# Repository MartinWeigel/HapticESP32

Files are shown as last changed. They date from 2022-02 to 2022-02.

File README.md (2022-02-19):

# HapticESP32

This PCB provides a maximum of eight ERM/LRA drivers and two transistors to control binary actuators.
All haptic actuators can be controlled through an [Adafruit Feather HUZZAH32](https://www.adafruit.com/product/3405) microcontroller.

All SMDs are on one-side of the PCB only to reduce costs for the assembly service.

This board was designed using [KiCad 6.0](http://www.kicad.org).

## Design
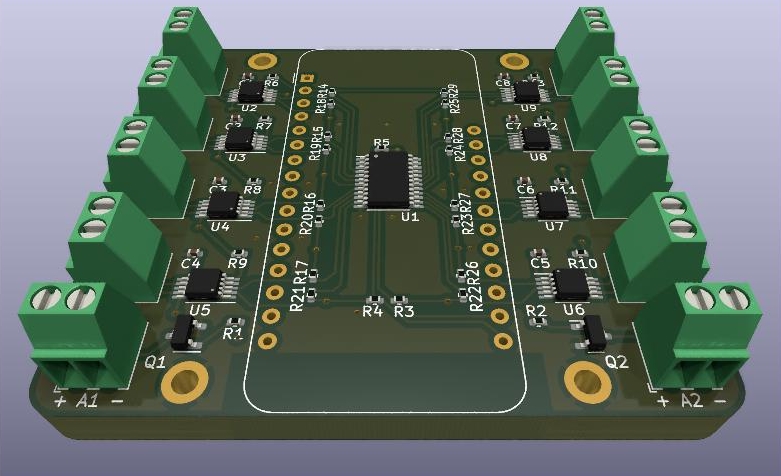
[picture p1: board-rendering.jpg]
Rendering of the board


## Parts
The part list is divided into two sections, the first one contains the parts if you decide to only solder the through-hole components yourself. The second BOM contains the SMD components.

### Through-hole components
Part                   | Quantity | Description
-----------------------|----------|-----------------------
Feather HUZZAH32       | 1        | ESP32 Microcontroller
Phoenix MPT-0,5-2-2.54 | 10       | 2-pin Terminalblock

### SMD components
Part               | Quantity | Description
-------------------|----------|-----------------
TCA9548APWR        | 1        | I2C Multiplexer
DRV2605LDGSR       | 8        | ERM/LRA Driver
MMBT5550LT1G       | 2        | NPN Transistor
Resistor 0402 1k   | 2        | Generic Resistor
Resistor 0402 4.7k | 27       | Generic Resistor
Capacitor 0402 1uF | 8        | Generic Capacitor

## License
<br />This work is licensed under a <a rel="license" href="http://creativecommons.org/licenses/by/4.0/">Creative Commons Attribution 4.0 International License</a>.

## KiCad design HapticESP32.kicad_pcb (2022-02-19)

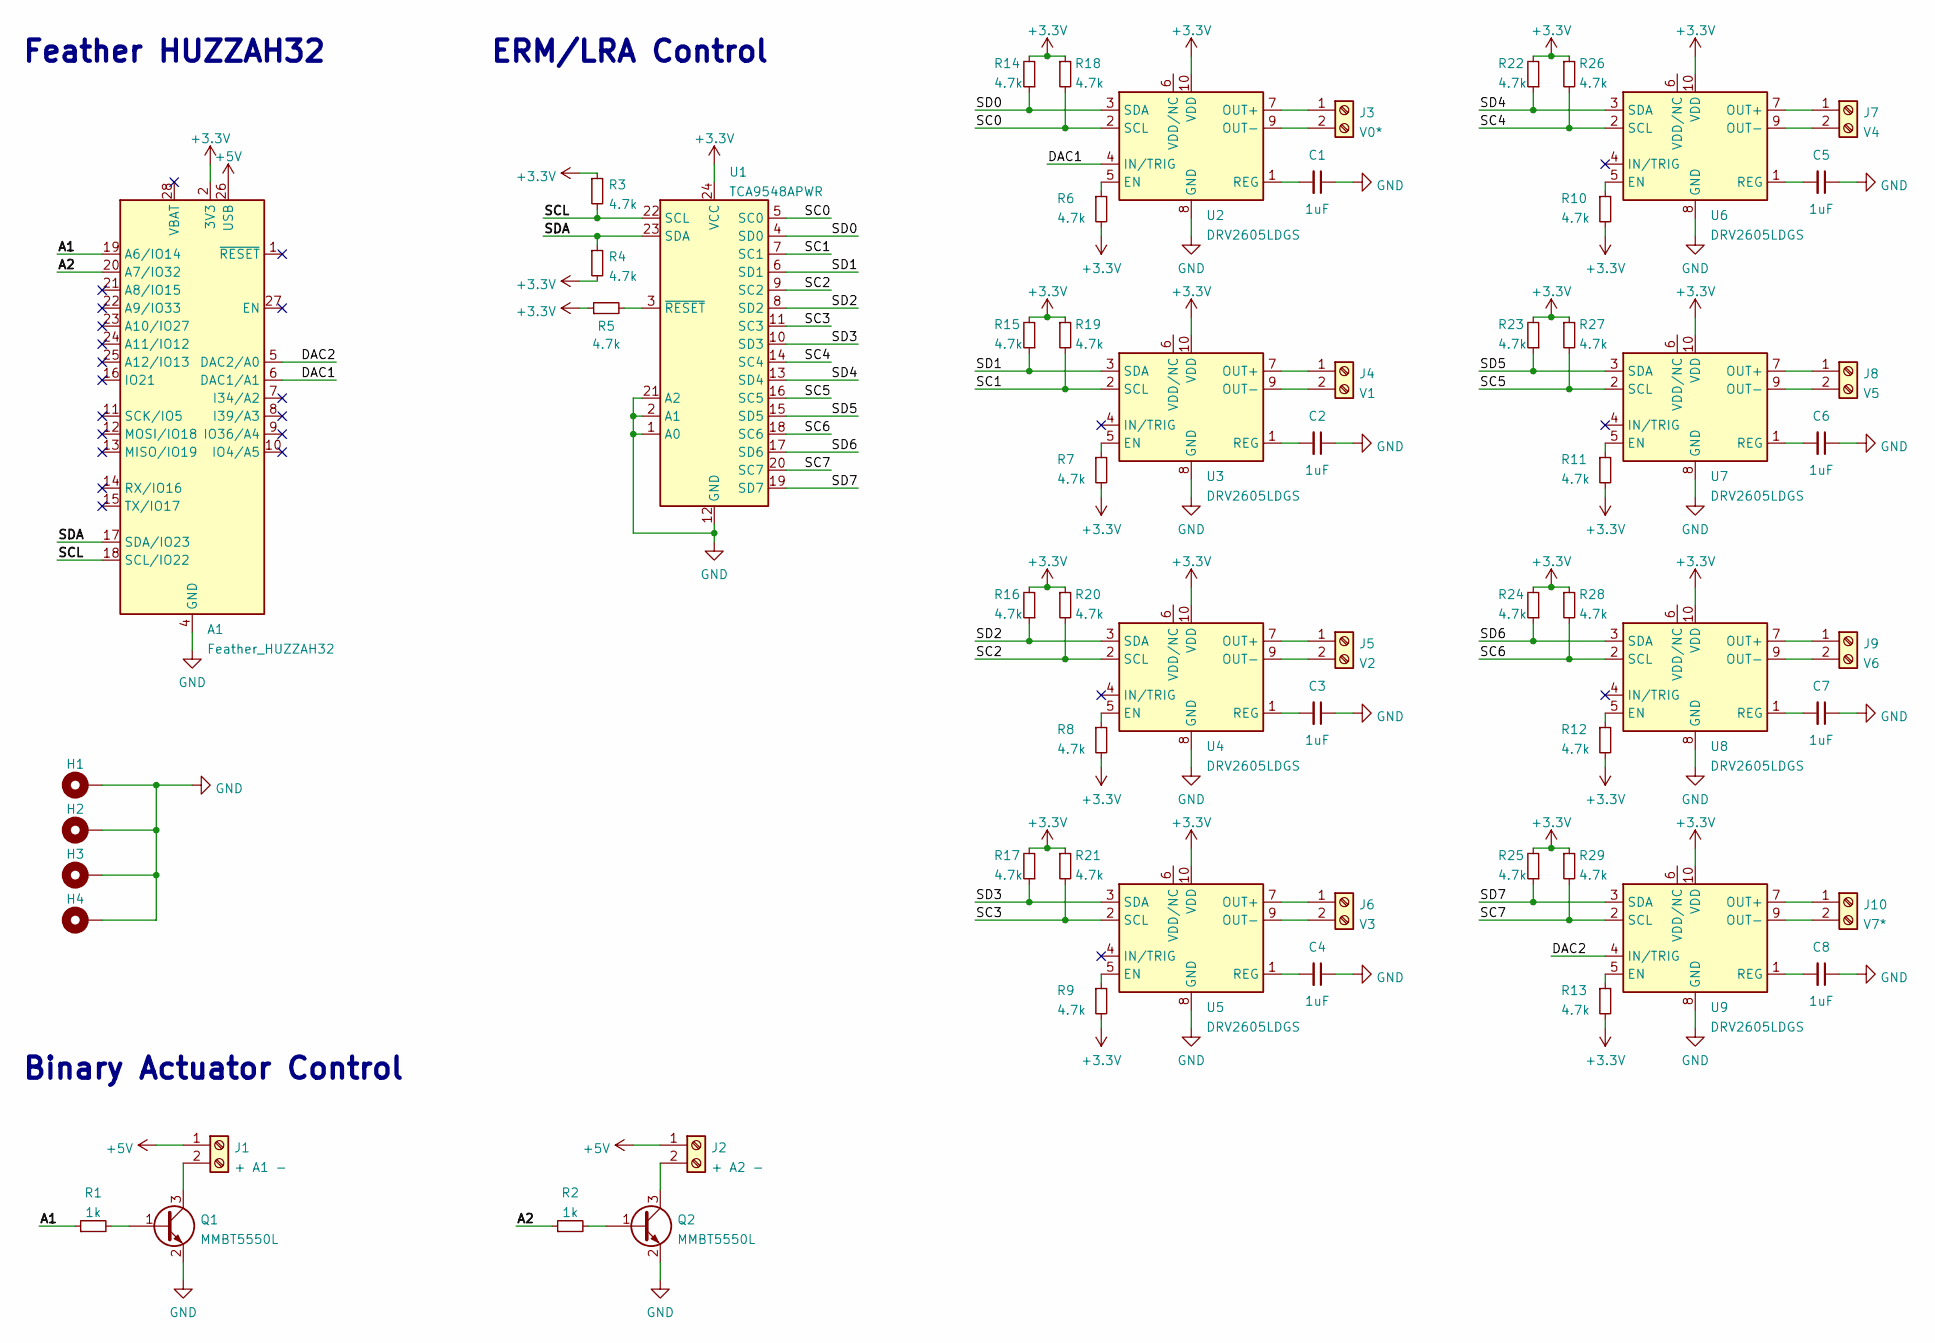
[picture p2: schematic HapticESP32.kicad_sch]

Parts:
A1: Feather_HUZZAH32; Adafruit_Feather
C1, C2, C3, C4, C5, C6, C7, C8: 1uF; C_0402_1005Metric
H1, H2, H3, H4: MountingHole_Pad; MountingHole_2.2mm_M2_DIN965_Pad
J1: + A1 -; TerminalBlock_Phoenix_MPT-0,5-2-2.54_1x02_P2.54mm_Horizontal
J2: + A2 -; TerminalBlock_Phoenix_MPT-0,5-2-2.54_1x02_P2.54mm_Horizontal
J3: V0*; TerminalBlock_Phoenix_MPT-0,5-2-2.54_1x02_P2.54mm_Horizontal
J4: V1; TerminalBlock_Phoenix_MPT-0,5-2-2.54_1x02_P2.54mm_Horizontal
J5: V2; TerminalBlock_Phoenix_MPT-0,5-2-2.54_1x02_P2.54mm_Horizontal
J6: V3; TerminalBlock_Phoenix_MPT-0,5-2-2.54_1x02_P2.54mm_Horizontal
J7: V4; TerminalBlock_Phoenix_MPT-0,5-2-2.54_1x02_P2.54mm_Horizontal
J8: V5; TerminalBlock_Phoenix_MPT-0,5-2-2.54_1x02_P2.54mm_Horizontal
J9: V6; TerminalBlock_Phoenix_MPT-0,5-2-2.54_1x02_P2.54mm_Horizontal
J10: V7*; TerminalBlock_Phoenix_MPT-0,5-2-2.54_1x02_P2.54mm_Horizontal
Q1, Q2: MMBT5550L; SOT-23
R1, R2: 1k; R_0402_1005Metric
R3, R4, R5, R6, R7, R8, R9, R10, R11, R12, R13, R14, R15, R16, R17, R18, R19, R20, R21, R22, R23, R24, R25, R26, R27, R28, R29: 4.7k; R_0402_1005Metric
U1: TCA9548APWR; TSSOP-24_4.4x7.8mm_P0.65mm
U2, U3, U4, U5, U6, U7, U8, U9: DRV2605LDGS; VSSOP-10_3x3mm_P0.5mm

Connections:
+3V3: A1.2 (3V3), R3.1, R4.2, R5.1, R6.2, R7.2, R8.2, R9.2, R10.2, R11.2, R12.2, R13.2, R14.2, R15.2, R16.2, R17.2, R18.1, R19.1, R20.1, R21.1, R22.2, R23.2, R24.2, R25.2, R26.1, R27.1, R28.1, R29.1, U1.24 (VCC), U2.10 (VDD), U3.10 (VDD), U4.10 (VDD), U5.10 (VDD), U6.10 (VDD), U7.10 (VDD), U8.10 (VDD), U9.10 (VDD)
+5V: A1.26 (USB), J1.1, J2.1
/A1: A1.19 (A6/IO14), R1.1
/A2: A1.20 (A7/IO32), R2.1
/DAC1: A1.6 (DAC1/A1), U2.4 (IN/TRIG)
/DAC2: A1.5 (DAC2/A0), U9.4 (IN/TRIG)
/SC0: R18.2, U1.5 (SC0), U2.2 (SCL)
/SC1: R19.2, U1.7 (SC1), U3.2 (SCL)
/SC2: R20.2, U1.9 (SC2), U4.2 (SCL)
/SC3: R21.2, U1.11 (SC3), U5.2 (SCL)
/SC4: R26.2, U1.14 (SC4), U6.2 (SCL)
/SC5: R27.2, U1.16 (SC5), U7.2 (SCL)
/SC6: R28.2, U1.18 (SC6), U8.2 (SCL)
/SC7: R29.2, U1.20 (SC7), U9.2 (SCL)
/SCL: A1.18 (SCL/IO22), R3.2, U1.22 (SCL)
/SD0: R14.1, U1.4 (SD0), U2.3 (SDA)
/SD1: R15.1, U1.6 (SD1), U3.3 (SDA)
/SD2: R16.1, U1.8 (SD2), U4.3 (SDA)
/SD3: R17.1, U1.10 (SD3), U5.3 (SDA)
/SD4: R22.1, U1.13 (SD4), U6.3 (SDA)
/SD5: R23.1, U1.15 (SD5), U7.3 (SDA)
/SD6: R24.1, U1.17 (SD6), U8.3 (SDA)
/SD7: R25.1, U1.19 (SD7), U9.3 (SDA)
/SDA: A1.17 (SDA/IO23), R4.1, U1.23 (SDA)
GND: A1.4 (GND), C1.1, C2.1, C3.1, C4.1, C5.1, C6.1, C7.1, C8.1, H1.1, H2.1, H3.1, H4.1, Q1.2 (E), Q2.2 (E), U1.1 (A0), U1.2 (A1), U1.12 (GND), U1.21 (A2), U2.8 (GND), U3.8 (GND), U4.8 (GND), U5.8 (GND), U6.8 (GND), U7.8 (GND), U8.8 (GND), U9.8 (GND)
unnamed: C1.2, U2.1 (REG)
unnamed: C2.2, U3.1 (REG)
unnamed: C3.2, U4.1 (REG)
unnamed: C4.2, U5.1 (REG)
unnamed: C5.2, U6.1 (REG)
unnamed: C6.2, U7.1 (REG)
unnamed: C7.2, U8.1 (REG)
unnamed: C8.2, U9.1 (REG)
unnamed: J1.2, Q1.3 (C)
unnamed: J2.2, Q2.3 (C)
unnamed: J3.1, U2.7 (OUT+)
unnamed: J3.2, U2.9 (OUT-)
unnamed: J4.1, U3.7 (OUT+)
unnamed: J4.2, U3.9 (OUT-)
unnamed: J5.1, U4.7 (OUT+)
unnamed: J5.2, U4.9 (OUT-)
unnamed: J6.1, U5.7 (OUT+)
unnamed: J6.2, U5.9 (OUT-)
unnamed: J7.1, U6.7 (OUT+)
unnamed: J7.2, U6.9 (OUT-)
unnamed: J8.1, U7.7 (OUT+)
unnamed: J8.2, U7.9 (OUT-)
unnamed: J9.1, U8.7 (OUT+)
unnamed: J9.2, U8.9 (OUT-)
unnamed: J10.1, U9.7 (OUT+)
unnamed: J10.2, U9.9 (OUT-)
unnamed: Q1.1 (B), R1.2
unnamed: Q2.1 (B), R2.2
unnamed: R5.2, U1.3 (~RESET)
unnamed: R6.1, U2.5 (EN)
unnamed: R7.1, U3.5 (EN)
unnamed: R8.1, U4.5 (EN)
unnamed: R9.1, U5.5 (EN)
unnamed: R10.1, U6.5 (EN)
unnamed: R11.1, U7.5 (EN)
unnamed: R12.1, U8.5 (EN)
unnamed: R13.1, U9.5 (EN)

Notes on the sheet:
ERM/LRA Control
Feather HUZZAH32
Binary Actuator Control

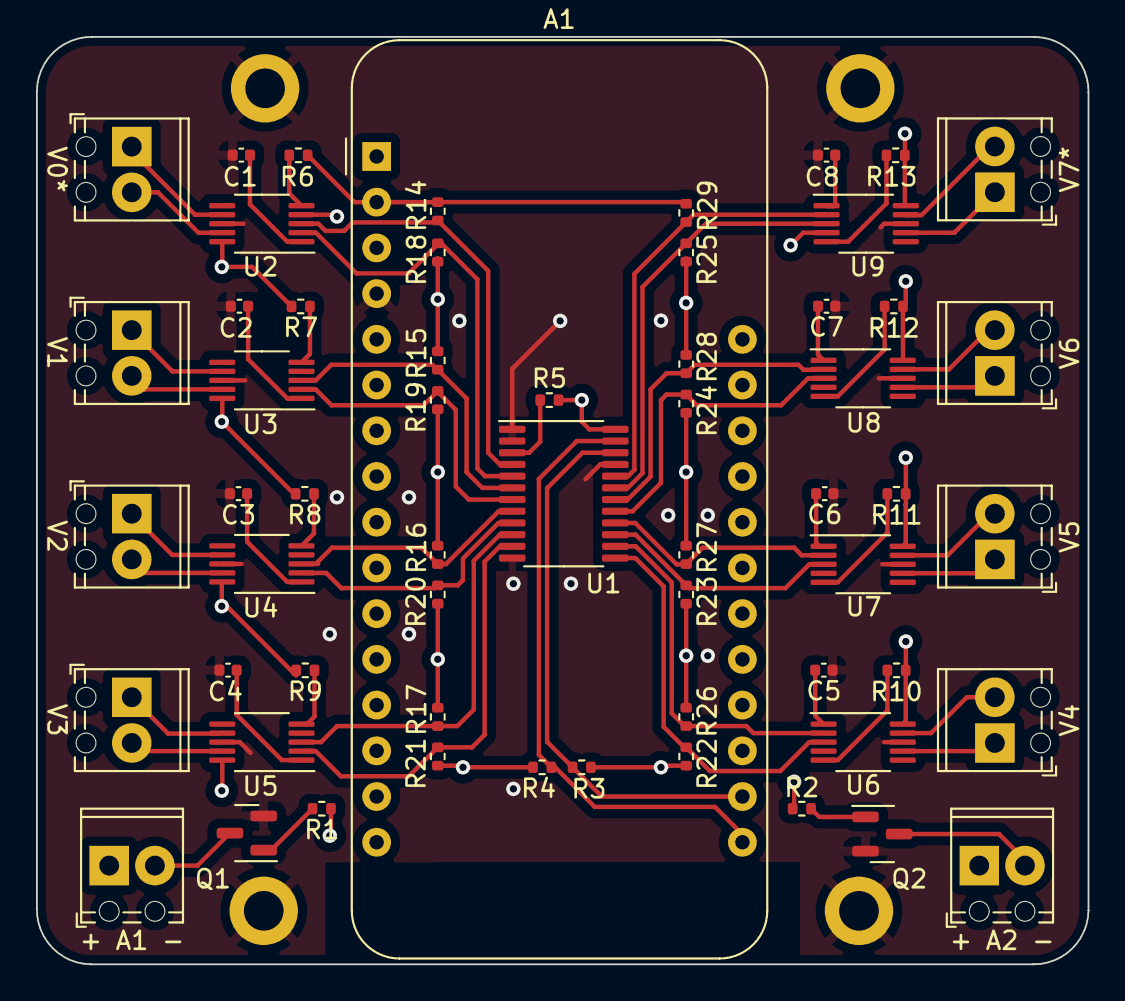
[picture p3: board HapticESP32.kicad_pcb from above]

Board: 4 copper layers, 58.4 x 51.5 mm, 63 parts (0 on the bottom side), 62 nets.

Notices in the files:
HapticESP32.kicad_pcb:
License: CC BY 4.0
